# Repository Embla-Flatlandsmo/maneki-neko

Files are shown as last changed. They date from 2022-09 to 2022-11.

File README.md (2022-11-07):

# Maneki Neko
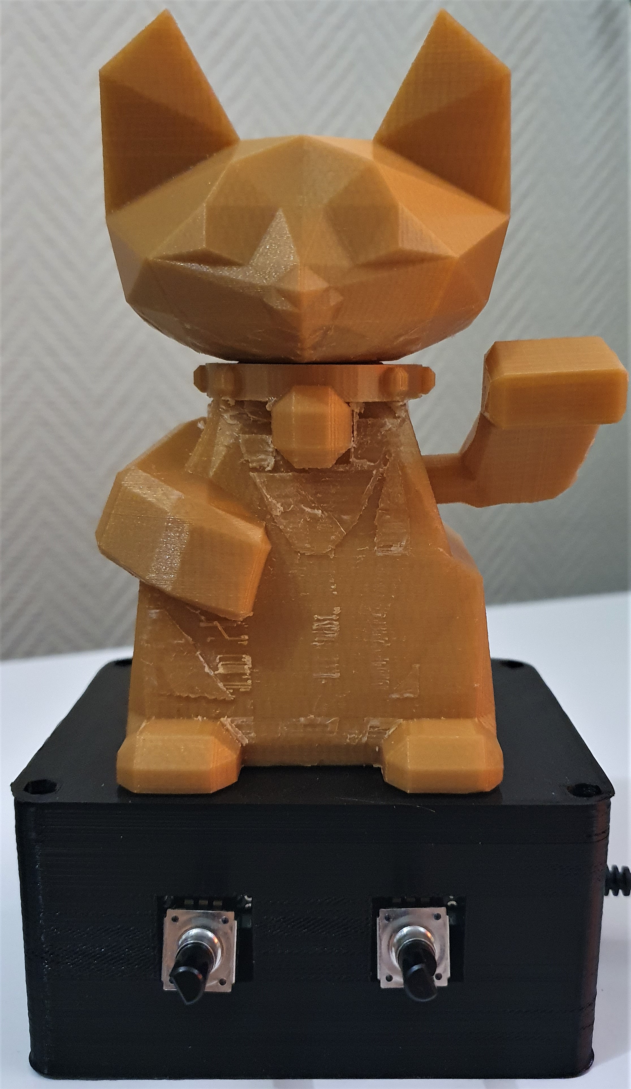
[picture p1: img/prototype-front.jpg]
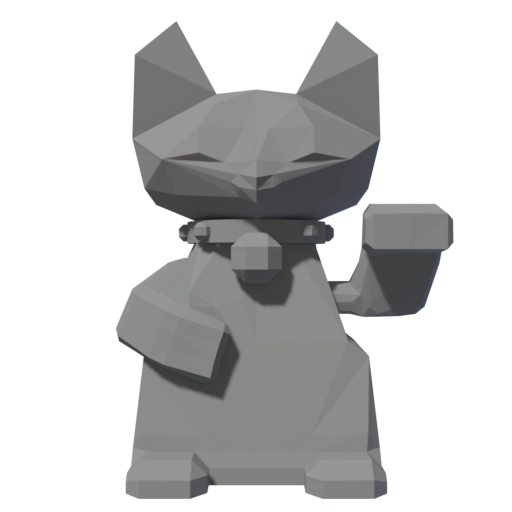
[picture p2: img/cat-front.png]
 

The 3D model is made by [Mats N. Olsen](https://www.matsnolsen.com/)

## Project structure
| Folder | Description |
| --- | --- |
| `code` | Software for the microcontroller unit |
| `production` | Models for 3D printing the parts |
| `schematics` | Images describing the way the electronics are wired |

## Hardware description
The project supports using both [nRF52840 DK](https://www.nordicsemi.com/Products/Development-hardware/nrf52840-dk) and [Adafruit ItsyBitsy nRF52840 Express](https://learn.adafruit.com/adafruit-itsybitsy-nrf52840-express). The enclosure is made for the ItsyBitsy, but `enclosure.scad` has been included so you can make it fit for a different board if you want.

### nRF 52840 DK
#### Wiring
| Pin | Name |
| --- | --- |
| P1.10 | Encoder 1 Line A |
| P1.11 | Encoder 1 Line B |
| P0.27 | Encoder 2 Line A |
| P0.26 | Encoder 2 Line B |
| P0.13 | Servo PWM output | 

### Adafruit ItsyBitsy nRF52840 Express
A full schematic has been made for the ItsyBitsy nRF52840 Express:

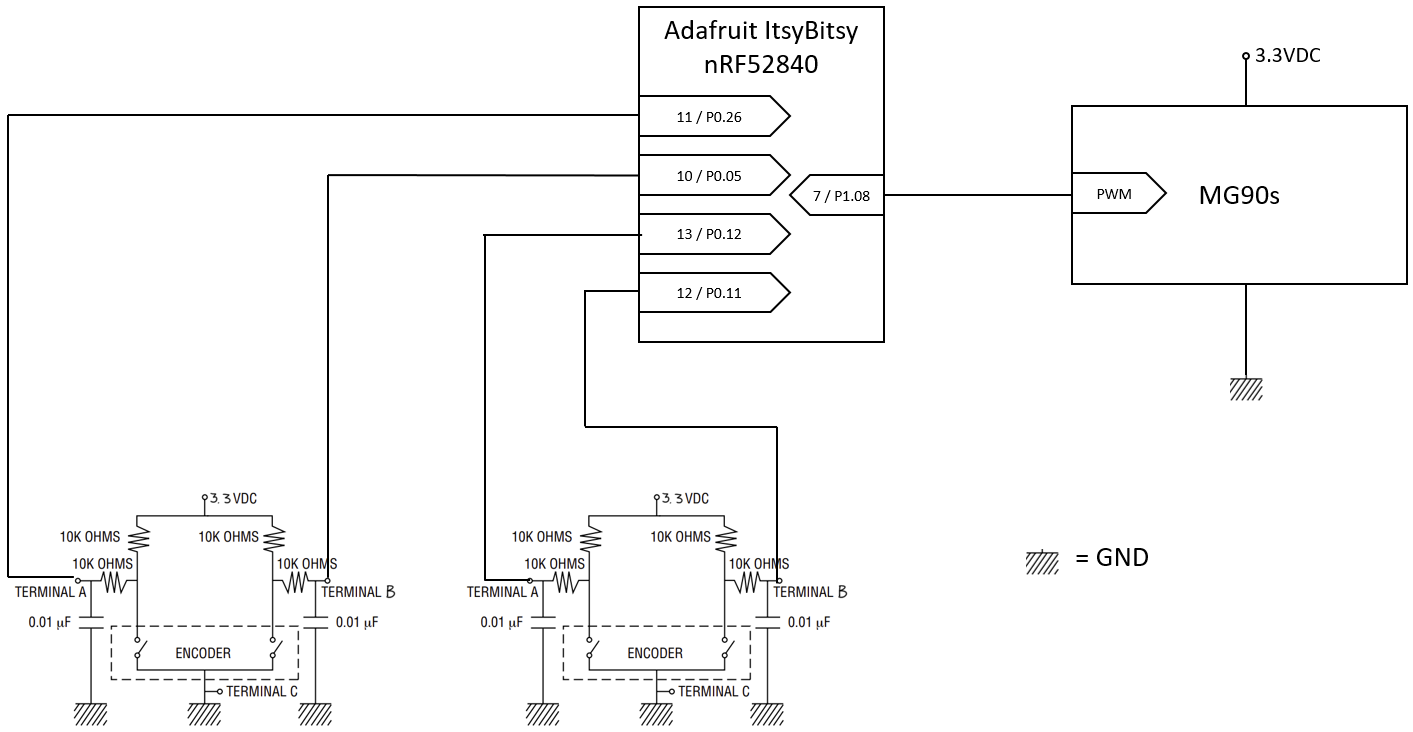
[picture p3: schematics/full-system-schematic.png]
Full system schematic for ItsyBitsy


#### Wiring
| Pin | Name |
| --- | --- |
| 13 | Encoder 1 Line A |
| 12 | Encoder 1 Line B |
| 11 | Encoder 2 Line A |
| 10 | Encoder 2 Line B |
| 7 | Servo PWM output | 

## Software Description
This project uses the [nRF Connect SDK v2.0.2](https://developer.nordicsemi.com/nRF_Connect_SDK/doc/2.0.2/nrf/index.html).
### Setup using the nRF Connect SDK Toolchain Manager
Prerequisite: [nRF Command Line Tools](https://www.nordicsemi.com/Products/Development-tools/nRF-Command-Line-Tools/Download?lang=en#infotabs)
1. **Install ncs v2.0.2**: Follow [nRF Connect SDK (ncs) setup tutorial](https://developer.nordicsemi.com/nRF_Connect_SDK/doc/2.0.2/nrf/gs_assistant.html) to install the nRF Connect SDK (ncs) toolchain.
2. Make sure you are able to build and program a basic project following [the nRF Connect SDK building tutorial](https://developer.nordicsemi.com/nRF_Connect_SDK/doc/latest/nrf/gs_programming.html)

3. **Clone this project into the ncs installation folder**: After installing nRF Connect SDK v2.0.2, open command prompt through the toolchain manager. Then, type `git clone https://github.com/Embla-Flatlandsmo/maneki-neko`

### First time setup for Adafruit ItsyBitsy nRF52840
Before building for the first time, you must copy the folder `code/boards/adafruit_itsybitsy_nrf52840` into the `boards/arm/` directory of your zephyr installation. 

> For example, if ncs is installed at `C:/ncs/v2.0.2` then you would copy the folder so it resides at `C:/ncs/v2.0.2/zephyr/boards/arm/adafruit_itsybitsy_nrf52840`

Before flashing, you must update the Adafruit UF2 bootloader [(see tutorial)](https://learn.adafruit.com/introducing-the-adafruit-nrf52840-feather/update-bootloader)

### Building and Flashing
Before building the project, make sure you are able to build and program a basic project following [the nRF Connect SDK building tutorial](https://developer.nordicsemi.com/nRF_Connect_SDK/doc/latest/nrf/gs_programming.html).

> For both of the boards, follow the steps for [building in the command line](https://developer.nordicsemi.com/nRF_Connect_SDK/doc/2.0.2/nrf/gs_programming.html#gs-programming-cmd).

#### Adafruit ItsyBitsy nRF52840 Express
1. Navigate to `maneki-neko/code` and build the program by calling `west build -b adafruit_itsybitsy_nrf52840`
2. Connect the ItsyBitsy to your host computer using USB
3. Tap the reset button twice quickly to enter bootloader mode
4. Flash the image by dragging and dropping the file `maneki-neko/code/build/zephyr/zephyr.uf2` into the `ITSY840BOOT` drive
5. The program should now run on your device

#### nRF52840 DK
1. Navigate to `maneki-neko/code` and build the program by calling `west build -b nrf52840dk_nrf52840`
2. Connect the nRF52840 DK to your computer using USB
3. Call `west flash`
4. The program should now run on your device

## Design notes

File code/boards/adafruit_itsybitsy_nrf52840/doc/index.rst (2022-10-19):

.. _adafruit_itsybitsy_nrf52840:

Adafruit ItsyBitsy nRF52840
#############################

Overview
********

The Adafruit ItsyBitsy nRF52840 Express is a small (36 mm x 18 mm) ARM
development board with an onboard RGB LED, USB port, 2 MB of QSPI flash,
and range of I/O broken out onto 21 GPIO pins.

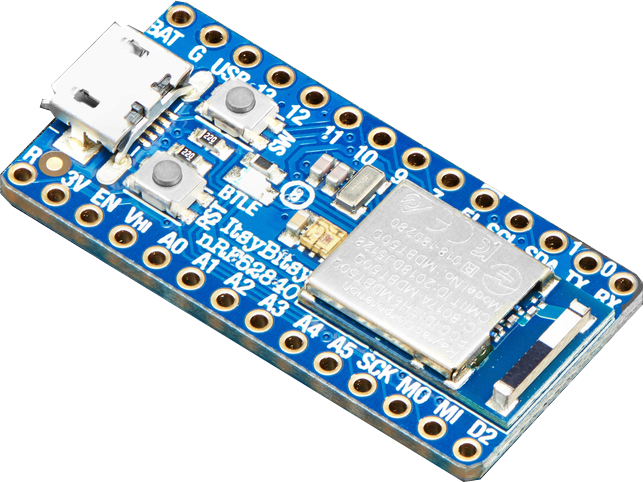
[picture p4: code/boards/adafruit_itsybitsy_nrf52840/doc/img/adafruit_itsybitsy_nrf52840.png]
Adafruit ItsyBitsy nRF52840 Express


Hardware
********
- nRF52840 ARM Cortex-M4F CPU at 64MHz
- 1 MB of flash memory and 256 KB of SRAM
- 2 MB of QSPI flash
- A user LED
- A user switch
- An RGB DotStar LED
- Native USB port
- One reset button

Supported Features
==================

The Adafruit Feather nRF52840 board configuration supports the
following hardware features:

+-----------+------------+----------------------+
| Interface | Controller | Driver/Component     |
+===========+============+======================+
| ADC       | on-chip    | adc                  |
+-----------+------------+----------------------+
| CLOCK     | on-chip    | clock_control        |
+-----------+------------+----------------------+
| FLASH     | on-chip    | flash                |
+-----------+------------+----------------------+
| GPIO      | on-chip    | gpio                 |
+-----------+------------+----------------------+
| I2C       | on-chip    | i2c                  |
+-----------+------------+----------------------+
| MPU       | on-chip    | arch/arm             |
+-----------+------------+----------------------+
| NVIC      | on-chip    | arch/arm             |
+-----------+------------+----------------------+
| PWM       | on-chip    | pwm                  |
+-----------+------------+----------------------+
| RADIO     | on-chip    | Bluetooth,           |
|           |            | ieee802154           |
+-----------+------------+----------------------+
| RTC       | on-chip    | system clock         |
+-----------+------------+----------------------+
| SPI       | on-chip    | spi                  |
+-----------+------------+----------------------+
| UART      | on-chip    | serial               |
+-----------+------------+----------------------+
| USB       | on-chip    | usb                  |
+-----------+------------+----------------------+
| WDT       | on-chip    | watchdog             |
+-----------+------------+----------------------+

Other hardware features have not been enabled yet for this board.

Connections and IOs
===================

The `Adafruit ItsyBitsy nRF52840 Express Learn site`_ has detailed
information about the board including `pinouts`_ and the `schematic`_.

LED
---

* LED0 (red) = P0.06
* LED1 (Adafruit DotStar)
    * DATA = P0.08
    * CLK = P1.09

Push buttons
------------

* SWITCH = P0.29
* RESET = P0.18

Testing LEDs and buttons on the Adafruit ItsyBitsy nRF52840 Express
*******************************************************************
The :ref:`button-sample` sample lets you test the buttons (switches) and the red LED.
The :ref:`blinky-sample` sample lets you test the red LED.

The DotStar LED has been implemented as a SPI device and can be tested
with the :ref:`led_apa102_sample` sample application.

You can build and flash the examples to make sure Zephyr is running correctly on
your board. The button and LED definitions can be found in
:zephyr_file:`boards/arm/adafruit_itsybitsy_nrf52840/adafruit_itsybitsy_nrf52840.dts`.

Programming and Debugging
*************************
The ItsyBitsy ships with the BOSSA compatible UF2 bootloader.  The
bootloader can be entered by quickly tapping the reset button twice.

First time setup
================
Some versions of this board were shipped with a buggy bootloader.
Ensure that the bootloader is up to date by following the
`Adafruit UF2 Bootloader update`_ tutorial.

Flashing
========
Flashing is done by dragging and dropping the built Zephyr UF2-file
into the :code:`ITSY840BOOT` drive.

#. Build the Zephyr kernel and the :ref:`blinky-sample`
   sample application:

   .. zephyr-app-commands::
      :zephyr-app: samples/basic/blinky
      :board: adafruit_itsybitsy_nrf52840
      :goals: build
      :compact:

#. Connect the ItsyBitsy to your host computer using USB

#. Tap the reset button twice quickly to enter bootloader mode

#. Flash the image:

   Drag and drop the file :code:`samples/basic/blinky/build/zephyr/zephyr.uf2`
   into :code:`ITSY840BOOT`

The device will disconnect and you should see the red LED blink.

References
**********

.. target-notes::

.. _Adafruit ItsyBitsy nRF52840 Express Learn site:
    https://learn.adafruit.com/adafruit-itsybitsy-nrf52840-express

.. _pinouts:
    https://learn.adafruit.com/adafruit-itsybitsy-nrf52840-express/pinouts

.. _schematic:
    https://learn.adafruit.com/adafruit-itsybitsy-nrf52840-express/downloads

.. _Adafruit UF2 Bootloader update:
    https://learn.adafruit.com/introducing-the-adafruit-nrf52840-feather/update-bootloader

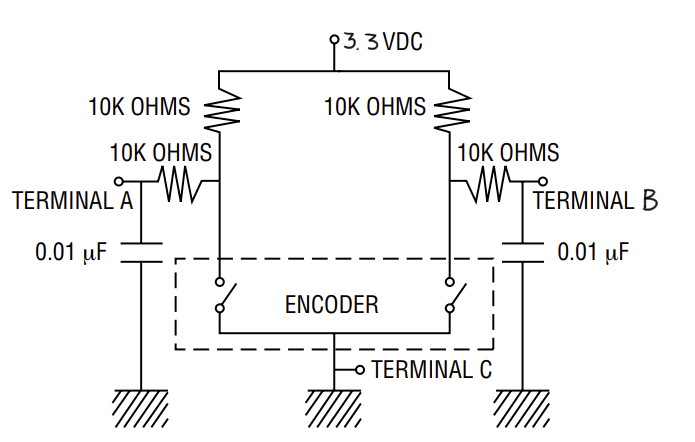
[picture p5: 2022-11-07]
schematics/single-encoder-circuit.png

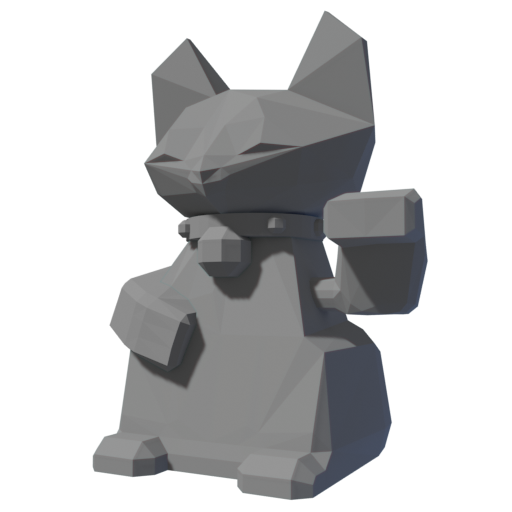
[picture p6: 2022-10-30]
img/cat-3-4.png

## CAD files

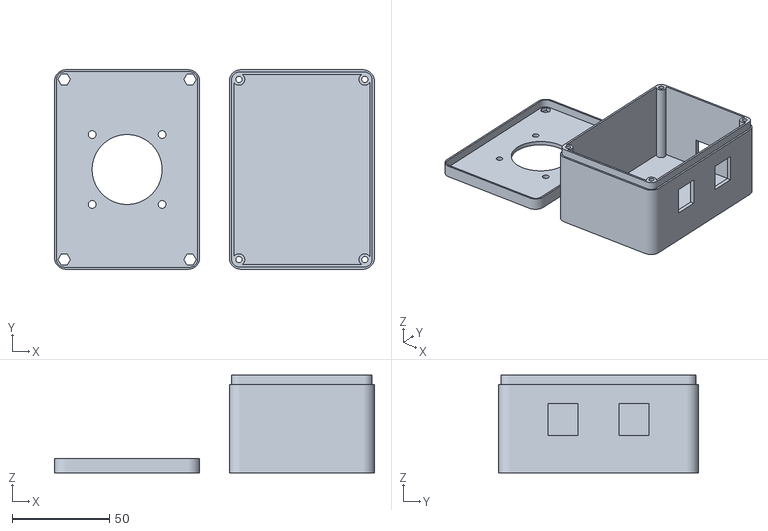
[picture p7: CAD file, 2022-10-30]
production/enclosure.stl
164.8 x 102.8 x 50.4

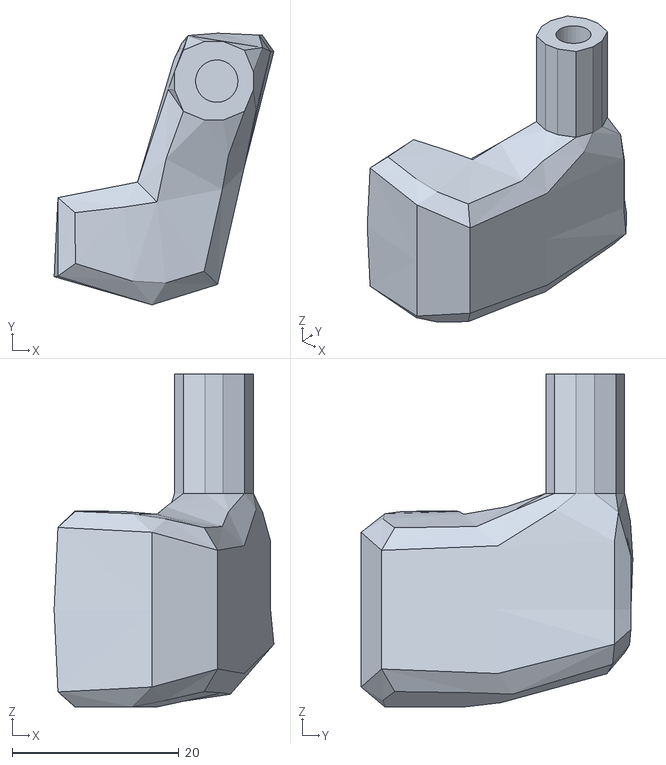
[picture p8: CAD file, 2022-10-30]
production/maneki-neko.stl
26.4 x 32.6 x 39.9

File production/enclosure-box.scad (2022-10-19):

$fn=100;




translate([-w/2-10,0,d+bpt+tpt])
rotate(a=180, v=[0,1,0])
box_top();
translate([w/2+10,0,0])
box_bottom();
             

//*************************************************//
//PARAMETERS
//*************************************************//
//BOX
//--------------------------------------------------
// For PLA printing, things should be in mulitples of 0.4 (standard nozzle thickness)
//inner box width + tolerances
w=70;
//inner box length + tolerances
h=98;
//inner box depth 
d=44;
//wall tickness
wt=2.4;
//bottom plate tickness
bpt=2.4;
//top plate tickness
tpt=2.4;
//top cutout depth
cd=4.8;
//top cutout tickness
cwt=1.2;
//--------------------------------------------------
//BOARD MOUNTING HOLES
//--------------------------------------------------
//position
cx=0;
cy=0;
//holes size (radius)
chs_i=1.5;
chs_o=4;
//distancer height
dsth=3;
//holes distance h
chd_h=90;
//holes distance v
chd_v=90;
//--------------------------------------------------
//TOP PART MOUNTING HOLES
//--------------------------------------------------
//position
cx1=0;
cy1=0;
//holes size (radius)
chs_i1=1.6;
chs_o1=3;
//holes distance h
chd_h1=h-2*chs_i1-2;
//holes distance v
chd_v1=w-2*chs_i1-2;


//--------------------------------------------------
//I/O HOLES
//--------------------------------------------------

usb_hole_padding = 2;
usb_hole_width = 10.6;
usb_hole_height = 8.5;
usb_offset_z = 12; // Offset to center of usb hole


encoder_hole_padding = 1;
encoder_hole_height = 13.5;
encoder_hole_width = 12.5;
encoder_hole_spacing = 24;
encoder_offset_z = 25; // Offset to center of encoder hole

top_hole_radius = 20;
//*************************************************//
//*************************************************//
//MODULES
//*************************************************//

//top box part          
module box_top()
{
        difference()
        {
            union()
            {
                difference()
                {
                    translate([ 0, 0, d+bpt-cd-0.2])     
                    rounded_cube( w+2*wt, h+2*wt, tpt+cd+0.2, 6);
                    
                    translate([ 0, 0,  d+bpt-cd-1])
                    rounded_cube( w+2*cwt+0.3, h+2*cwt+0.3, cd+1, 4);
                }
                /*************************/
                
                //add here...
                
                /*************************/
            }
            //TOP PART HOLES
            tph_t_cut();
            /*************************/
            
            //subtract here... 
            tph_t_electronics_hole();
            /*************************/ 
        }
}
//bottom box
module box_bottom()
{
    difference()
    {
        union()
        {
            difference()
            {
                rounded_cube( w+2*wt, h+2*wt, d+bpt, 6);
                
                translate([ 0, 0, -cd])
                difference()
                {
                    translate([ 0, 0,  d+bpt])
                    rounded_cube( w+2*wt+1, h+2*wt+1, cd+1, 4);

                    translate([ 0, 0,  d+bpt-1])
                    rounded_cube( w+2*cwt, h+2*cwt, cd+3, 4);
                }
                translate([ 0, 0, bpt])
                rounded_cube( w, h, d+bpt, 4);
            }
            //BOARD DISTANCER
            //board_distancer();
            //TOP PLATE DISTANCER
            top_distancer();
            /*************************/
            
            //add here...
            
            /*************************/
        }
        
        //BOARD HOLES
        //bh_cut();
        //TOP PART HOLES
        tph_b_cut();
        /*************************/
        
        //subtract here...
        bh_io_usb();
        bh_io_holes();
        /*************************/
  
    }
}

/****************************************************/
module board_distancer()
{
    translate([cx,cy,0])
    {              
        translate([+chd_h/2,chd_v/2,0])
        cylinder(r=chs_o,h=bpt+dsth);
        translate([-chd_h/2,chd_v/2,0])
        cylinder(r=chs_o,h=bpt+dsth);
        translate([+chd_h/2,-chd_v/2,0])
        cylinder(r=chs_o,h=bpt+dsth);
        translate([-chd_h/2,-chd_v/2,0])
        cylinder(r=chs_o,h=bpt+dsth);
    }
}
module top_distancer()
{
    translate([cx1,cy1,0])
    {
        translate([-chd_v1/2, chd_h1/2, 0])   
        cylinder(r=chs_o1,h=d+bpt);
        translate([-chd_v1/2, -chd_h1/2, 0])   
        cylinder(r=chs_o1,h=d+bpt);
        translate([chd_v1/2, chd_h1/2, 0])   
        cylinder(r=chs_o1,h=d+bpt);
        translate([chd_v1/2, -chd_h1/2, 0])   
        cylinder(r=chs_o1,h=d+bpt);
    }
}
module bh_cut()
{
    translate([cx,cy,0])
    {  
        translate([-chd_h/2,-chd_v/2,-1])
        cylinder(r=chs_i,h=bpt+dsth+2);
        translate([+chd_h/2,-chd_v/2,-1])
        cylinder(r=chs_i,h=bpt+dsth+2);
        translate([-chd_h/2,chd_v/2,-1])
        cylinder(r=chs_i,h=bpt+dsth+2);
        translate([+chd_h/2,chd_v/2,-1])
        cylinder(r=chs_i,h=bpt+dsth+2);
        
        translate([-chd_h/2,-chd_v/2,1.3])
        fhex(5.5,3);
        translate([+chd_h/2,-chd_v/2,1.3])
        fhex(5.5,3);
        translate([-chd_h/2,chd_v/2,1.3])
        fhex(5.5,3);
        translate([+chd_h/2,chd_v/2,1.3])
        fhex(5.5,3);
    }
}


module bh_io_holes()
{
    bh_encoder_hole();
    mirror([0, 1, 0])
        bh_encoder_hole();
}

module bh_encoder_hole()
{
    translate([
    w/2+wt/2, 
    encoder_hole_spacing/2+encoder_hole_width/2+encoder_hole_padding, 
    bpt+encoder_offset_z+encoder_hole_padding
    ])
        cube([2*wt, encoder_hole_width+encoder_hole_padding, encoder_hole_height+encoder_hole_padding], center=true);
}

module bh_io_usb()
{
    
    translate([0, h/2+wt/2, bpt+usb_offset_z+usb_hole_padding])
        cube([usb_hole_width+usb_hole_padding, 2*wt, bpt+usb_hole_height+usb_hole_padding], center=true);
}

module tph_t_electronics_hole()
{
    translate([ 0, 0, d]) 
        cylinder(h=4*tpt, r=top_hole_radius);
}

module tph_t_cut()
{
    translate([cx1,cy1,0])
    {
        translate([-chd_v1/2, chd_h1/2, -2])   
        cylinder(r=chs_i1,h=d+bpt+tpt+3);
        translate([chd_v1/2, chd_h1/2, -2])   
        cylinder(r=chs_i1,h=d+bpt+tpt+3);
    
        translate([-chd_v1/2, -chd_h1/2, -2])   
        cylinder(r=chs_i1,h=d+bpt+tpt+3);
        translate([chd_v1/2, -chd_h1/2, -2])   
        cylinder(r=chs_i1,h=d+bpt+tpt+3);
        
        translate([-chd_v1/2, chd_h1/2, d+bpt+tpt-1.3]) 
        fhex(5.5,3);
        
        translate([chd_v1/2, chd_h1/2, d+bpt+tpt-1.3])  
        fhex(5.5,3);
    
        translate([-chd_v1/2, -chd_h1/2, d+bpt+tpt-1.3])   
        fhex(5.5,3);
        
        translate([chd_v1/2, -chd_h1/2, d+bpt+tpt-1.3])   
        fhex(5.5,3);
    
    }   
}
module tph_b_cut()
{
    translate([cx1,cy1,0])
    {
        translate([-chd_v1/2, chd_h1/2, -2])   
        cylinder(r=chs_i1,h=d+bpt+3);
        translate([chd_v1/2, chd_h1/2, -2])   
        cylinder(r=chs_i1,h=d+bpt+3);
    
        translate([-chd_v1/2, -chd_h1/2, -2])   
        cylinder(r=chs_i1,h=d+bpt+3);
        translate([chd_v1/2, -chd_h1/2, -2])   
        cylinder(r=chs_i1,h=d+bpt+3);
        
        //translate([-chd_v1/2, chd_h1/2, -1]) 
        //cylinder(r=3,h=4);
        
        //translate([chd_v1/2, chd_h1/2, -1])  
        //cylinder(r=3,h=4);
    
        //translate([-chd_v1/2, -chd_h1/2, -1])   
        //cylinder(r=3,h=4);
        
        //translate([chd_v1/2, -chd_h1/2, -1])   
        //cylinder(r=3,h=4); 
    
    }   
}


module rounded_cube( x, y, z, r)
{
    translate([-x/2+r,-y/2+r,0])
    linear_extrude(height=z)
    minkowski() 
    {
        square([x-2*r,y-2*r],true);
        translate([x/2-r,y/2-r,0])
        circle(r);

    }
}

module fhex(wid,height)
{
    hull()
    {
        cube([wid/1.7,wid,height],center = true);
        rotate([0,0,120])cube([wid/1.7,wid,height],center = true);
        rotate([0,0,240])cube([wid/1.7,wid,height],center = true);
    }
}

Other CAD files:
production/enclosure.scad

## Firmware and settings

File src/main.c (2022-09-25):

/*
 * Copyright (c) 2019 Nordic Semiconductor ASA
 *
 * SPDX-License-Identifier: LicenseRef-Nordic-5-Clause
 */

#include <app_event_manager.h>
#include <zephyr/logging/log.h>

#define MODULE main

LOG_MODULE_REGISTER(MODULE);

void main(void)
{
	if (app_event_manager_init()) {
		LOG_ERR("Application Event Manager not initialized");
	} else {
		// module_set_state(MODULE_STATE_READY);
	}
}

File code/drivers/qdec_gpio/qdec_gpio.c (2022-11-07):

#include <devicetree.h>
#include <drivers/sensor.h>
#include <drivers/gpio.h>

#include <logging/log.h>
LOG_MODULE_REGISTER(sensor_qdec_gpio, CONFIG_SENSOR_LOG_LEVEL);

#define DT_DRV_COMPAT nordic_qdec_gpio
#define QDEC_GPIO_INIT_PRIORITY 41

#define FULL_ANGLE 360

struct qdec_gpio_cb_container
{
    struct gpio_callback cb;
    struct device *dev;
};

struct qdec_gpio_data
{
    uint8_t prev_state_a;
    uint8_t prev_state_b;
    int32_t counter;
    int32_t fetched_counter;
    sensor_trigger_handler_t data_ready_handler;
};

struct qdec_gpio_conf
{
    struct gpio_dt_spec gpio_a;
    struct qdec_gpio_cb_container gpio_a_cb_c;
    struct gpio_dt_spec gpio_b;
    struct qdec_gpio_cb_container gpio_b_cb_c;
    int32_t ticks_per_rotation;
};

static int qdec_gpio_sample_fetch(const struct device *dev, enum sensor_channel chan)
{
    if (!(chan == SENSOR_CHAN_ALL || chan == SENSOR_CHAN_ROTATION))
    {
        LOG_ERR("Invalid channel %d. Only SENSOR_CHAN_ALL and SENSOR_CHAN_ROTATION are supported.", chan);
        return -ENOTSUP;
    }

    struct qdec_gpio_data *data = dev->data;
    unsigned int key = irq_lock();
    data->fetched_counter = data->counter;
    irq_unlock(key);

    return 0;
}

static int qdec_gpio_channel_get(const struct device *dev, enum sensor_channel chan, struct sensor_value *val)
{
    if (chan != SENSOR_CHAN_ROTATION)
    {
        LOG_ERR("Invalid channel %d. Only SENSOR_CHAN_ROTATION is supported.", chan);
        return -ENOTSUP;
    }

    const struct qdec_gpio_conf *conf = dev->config;
    const struct qdec_gpio_data *data = dev->data;

    int32_t steps = conf->ticks_per_rotation;

    int32_t counter = data->fetched_counter;

    val->val1 = (counter * FULL_ANGLE) / steps;

    val->val2 = (counter * FULL_ANGLE) % steps;
    val->val2 *= 1000000;
    val->val2 /= steps;
    return 0;
}

static int qdec_gpio_trigger_set(const struct device *dev, const struct sensor_trigger *trig, sensor_trigger_handler_t handler)
{
    struct qdec_gpio_data *data = dev->data;

    if (trig->type != SENSOR_TRIG_DATA_READY)
    {
        LOG_ERR("Invalid trigger type %d. Only SENSOR_TRIG_DATA_READY is supported.", trig->type);
        return -ENOTSUP;
    }

    if ((trig->chan != SENSOR_CHAN_ALL) &&
        (trig->chan != SENSOR_CHAN_ROTATION))
    {
        LOG_ERR("Invalid trigger channel %d. Only SENSOR_CHAN_ROTATION is supported.", trig->chan);
        return -ENOTSUP;
    }

    unsigned int key = irq_lock();
    data->data_ready_handler = handler;
    irq_unlock(key);

    return 0;
}

static void qdec_line_callback(const struct device *port, struct gpio_callback *cb, uint32_t pins)
{
    // Decoding partially taken from https://electronics.stackexchange.com/a/360638
    static int8_t lookup_table[16] = {
        0, // 00 to 00
       -1, // 00 to 01
        1, // 00 to 10
        2, // 00 to 11

        1, // 01 to 00 
        0, // 01 to 01
        2, // 01 to 10
       -1, // 01 to 11

       -1, // 10 to 00 
        2, // 10 to 01
        0, // 10 to 10
        1, // 10 to 11

        2, // 11 to 00
        1, // 11 to 01
       -1, // 11 to 10
        0  // 11 to 11
    };

    struct device *dev = CONTAINER_OF(cb, struct qdec_gpio_cb_container, cb)->dev;
    struct qdec_gpio_data *data = dev->data;
    struct qdec_gpio_conf *conf = dev->config;

    uint8_t old_a = data->prev_state_a;
    uint8_t old_b = data->prev_state_b;

    uint8_t new_a = gpio_pin_get(port, conf->gpio_a.pin);
    uint8_t new_b = gpio_pin_get(port, conf->gpio_b.pin);

    data->prev_state_a = new_a;
    data->prev_state_b = new_b;
    uint8_t movement_index = (old_a << 3) + (old_b << 2) + (new_a << 1) + new_b;
    if (lookup_table[movement_index] > 1)
    {
        LOG_WRN("Quadrature decoder made invalid transition. old_a: %d, old_b: %d, new_a: %d, new_b: %d", old_a, old_b, new_a, new_b);
        return;
    }

    data->counter += lookup_table[movement_index];

    if (data->data_ready_handler)
    {
        struct sensor_trigger trig = {
            .type = SENSOR_TRIG_DATA_READY,
            .chan = SENSOR_CHAN_ROTATION,
        };
        data->data_ready_handler(dev, &trig);
    }
}
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

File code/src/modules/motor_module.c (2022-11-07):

/*
 * Copyright (c) 2018 - 2019 Nordic Semiconductor ASA
 *
 * SPDX-License-Identifier: LicenseRef-Nordic-5-Clause
 */

#include <assert.h>
#include <limits.h>

#include <zephyr/kernel.h>
#include <zephyr/types.h>

#include <zephyr/sys/util.h>
#include <device.h>
#include <drivers/pwm.h>

#include "events/encoder_module_event.h"
#include <caf/events/module_state_event.h>

#define MODULE motor_module

#include <zephyr/logging/log.h>
LOG_MODULE_REGISTER(MODULE, CONFIG_MOTOR_MODULE_LOG_LEVEL);

static const struct pwm_dt_spec servo = PWM_DT_SPEC_GET(DT_NODELABEL(servo));
static const uint32_t min_pulse = DT_PROP(DT_NODELABEL(servo), min_pulse);
static const uint32_t max_pulse = DT_PROP(DT_NODELABEL(servo), max_pulse);

static const uint32_t pulse_range = (max_pulse-min_pulse)/2;

#if IS_ENABLED(CONFIG_MOTOR_MODULE_USE_BTN_INPUT)
#include <caf/events/button_event.h>
#define BTN_INCREASE_PERIOD 0
#define BTN_DECREASE_PERIOD 2
#define BTN_INCREASE_AMPLITUDE 1
#define BTN_DECREASE_AMPLITUDE 3
#endif /* CONFIG_MOTOR_MODULE_USE_BTN_INPUT */

#define AMPLITUDE_STEP CONFIG_MOTOR_MODULE_AMPLITUDE_STEP
#define PERIOD_STEP CONFIG_MOTOR_MODULE_PERIOD_STEP

#define MAX_PERIOD_MSEC CONFIG_MOTOR_MODULE_MAX_PERIOD_MSEC
#define MIN_PERIOD_MSEC CONFIG_MOTOR_MODULE_MIN_PERIOD_MSEC

uint32_t amplitude = 100;
uint32_t motor_time_period_msec = MIN_PERIOD_MSEC;

/*================= UTILITY FUNCTIONS =================*/

/**
 * @brief Maps a value in range [input_start, input_end] to the range [output_start, output_end]
 * 
 * @param input value to map
 * @param input_start Start of value range (minimum)
 * @param input_end End of value range (maximum)
 * @param output_start Start of new range (minimum)
 * @param output_end End of new range (maximum)
 * @return uint32_t Value, in new range
 */
uint32_t map_range(uint32_t input, uint32_t input_start, uint32_t input_end, uint32_t output_start, uint32_t output_end)
{
    return output_start + ((output_end - output_start) / (input_end - input_start)) * (input - input_start);
}

static void update_period(float value)
{
    if (value > 0) 
    {
        if (motor_time_period_msec >= MAX_PERIOD_MSEC)
        {
            motor_time_period_msec = MAX_PERIOD_MSEC;
            LOG_DBG("Max period width reached.");
            return;
        }
        motor_time_period_msec += PERIOD_STEP;
        LOG_DBG("increasing period");
        return;
    }

    if (value < 0) 
    {
        if (motor_time_period_msec <= MIN_PERIOD_MSEC)
        {
            motor_time_period_msec = MIN_PERIOD_MSEC;
            LOG_DBG("Min period width reached.");
            return;
        }
        motor_time_period_msec -= PERIOD_STEP;
        LOG_DBG("Decreasing period");
        return;
    }
    return;
}

static void update_amplitude(float value) 
{
    if (value > 0) {
        if (amplitude >= 100)
        {
            amplitude = 100;
            LOG_DBG("Max amplitude reached.");
            return;
        }
        amplitude += AMPLITUDE_STEP;
        LOG_DBG("Increasing amplitude");
        return;
    }

    if (value < 0) {
        if (amplitude <= 0)
        {
            amplitude = 0;
            LOG_DBG("Min amplitude reached.");
            return;
        }
        amplitude -= AMPLITUDE_STEP;
        LOG_DBG("Decreasing Amplitude");
        return;
    }

    return;
}


/*================= EVENT HANDLERS =================*/

static bool handle_encoder_module_event(const struct encoder_module_event *evt)
{
    switch (evt->type)
    {
        case ENCODER_A_EVT_DATA_SEND:
            update_period(evt->data.rot_val);
            break;
        case ENCODER_B_EVT_DATA_SEND:
            update_amplitude(evt->data.rot_val);
            break;
        default:
            break;
    }
    return false;
}


#if IS_ENABLED(CONFIG_MOTOR_MODULE_USE_BTN_INPUT)
static bool handle_button_event(const struct button_event *evt)
{
	if (evt->pressed) {
		switch (evt->key_id) {
		case BTN_INCREASE_PERIOD:
            update_period(1.0);
			break;
		case BTN_DECREASE_PERIOD:
            update_period(-1.0);
			break;
        case BTN_INCREASE_AMPLITUDE:
            update_amplitude(1.0);
            break;
        case BTN_DECREASE_AMPLITUDE:
            update_amplitude(-1.0);
            break;
		default:
			break;
		}
	}
	return false;
}
#endif /* CONFIG_MOTOR_MODULE_USE_BTN_INPUT */

static bool app_event_handler(const struct app_event_header *aeh)
{
    if (is_encoder_module_event(aeh))
    {
        return handle_encoder_module_event(cast_encoder_module_event(aeh));
    }

#if IS_ENABLED(CONFIG_MOTOR_MODULE_USE_BTN_INPUT)
	if (is_button_event(aeh)) {
		return handle_button_event(cast_button_event(aeh));
	}
#endif /* CONFIG_MOTOR_MODULE_USE_BTN_INPUT */

	if (is_module_state_event(aeh)) {
        /* No setup necessary since it is done in module_thread_fn */
		return false;
	}
	/* Event not handled but subscribed. */
	__ASSERT_NO_MSG(false);
    return false;

}

/*================= MODULE THREAD =================*/
static int setup(void)
{
	int ret;

	if (!device_is_ready(servo.dev)) {
		LOG_ERR("Error: PWM device %s is not ready\n", servo.dev->name);
		return 0;
	}
    return 0;
}

static void module_thread_fn(void)
{
    LOG_DBG("Initializing motor module.");
    LOG_DBG("Pulse width: [%d, %d] (ns)", min_pulse, max_pulse);
    LOG_DBG("Arm rotation period range: [%d, %d] (ms)", MIN_PERIOD_MSEC, MAX_PERIOD_MSEC);
	int err;

	err = setup();
	if (err) {
		LOG_ERR("setup, error: %d", err);
	}

    int ret;
    static int up_or_down = 1;

    while(true)
    {   
        uint32_t pulse_width_offset = map_range(amplitude, 0, 100, 0, pulse_range);
        uint32_t pulse_width = min_pulse+pulse_range+up_or_down*pulse_width_offset;
        up_or_down *= -1;
        ret = pwm_set_pulse_dt(&servo, pulse_width);
		if (ret < 0) {
			LOG_ERR("Error %d: failed to set pulse width\n", ret);
			return;
		}
        k_sleep(K_MSEC(motor_time_period_msec));
    }
}

K_THREAD_DEFINE(motor_module_thread, CONFIG_MOTOR_THREAD_STACK_SIZE,
		module_thread_fn, NULL, NULL, NULL,
		K_HIGHEST_APPLICATION_THREAD_PRIO, 0, 0);
APP_EVENT_LISTENER(MODULE, app_event_handler);
APP_EVENT_SUBSCRIBE(MODULE, encoder_module_event);
APP_EVENT_SUBSCRIBE(MODULE, module_state_event);

#if IS_ENABLED(CONFIG_MOTOR_MODULE_USE_BTN_INPUT)
APP_EVENT_SUBSCRIBE(MODULE, button_event);
#endif /* CONFIG_MOTOR_MODULE_USE_BTN_INPUT */

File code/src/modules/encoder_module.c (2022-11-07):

/*
 * Copyright (c) 2021 Nordic Semiconductor ASA
 *
 * SPDX-License-Identifier: LicenseRef-Nordic-5-Clause
 */


#include <zephyr/kernel.h>

#define MODULE encoder_module
#include <caf/events/module_state_event.h>
#include <app_event_manager.h>
#include <zephyr/settings/settings.h>
#include <drivers/sensor.h>
#include "modules_common.h"
#include "events/encoder_module_event.h"

#include <zephyr/logging/log.h>
LOG_MODULE_REGISTER(MODULE, CONFIG_ENCODER_MODULE_LOG_LEVEL);

static const int64_t minimum_update_interval_msec = (1000/CONFIG_ENCODER_MAX_MESSAGE_FREQUENCY);

static struct sensor_trigger trig_a;
static struct sensor_trigger trig_b;

static double rot_a;
static double rot_b;
static int64_t encoder_a_delta_time;
static int64_t encoder_b_delta_time;

static void trigger_a_handler(const struct device *dev, const struct sensor_trigger* trig)
{
	struct sensor_value rot;
	int err;
	err = sensor_sample_fetch(dev);
	if (err != 0)
	{
		LOG_ERR("sensor_sample_fetch error: %d\n", err);
		return;
	}
	err = sensor_channel_get(dev, SENSOR_CHAN_ROTATION, &rot);
	if (err != 0)
	{
		LOG_ERR("sensor_channel_get error: %d\nF", err);
		return;
	}

	double new_rot_a = sensor_value_to_double(&rot);
	float delta_rot = rot_a - new_rot_a;
	rot_a = new_rot_a;

	int64_t delta_time_a = k_uptime_delta(&encoder_a_delta_time);
	if (delta_time_a >= minimum_update_interval_msec) {
		struct encoder_module_event *encoder_module_event = new_encoder_module_event();
		encoder_module_event->type = ENCODER_A_EVT_DATA_SEND;
		encoder_module_event->data.rot_val = delta_rot;
		APP_EVENT_SUBMIT(encoder_module_event);
	}
}

static void trigger_b_handler(const struct device *dev, const struct sensor_trigger* trig)
{
	struct sensor_value rot;
	int err;
	err = sensor_sample_fetch(dev);
	if (err != 0)
	{
		LOG_ERR("sensor_sample_fetch error: %d\n", err);
		return;
	}
	err = sensor_channel_get(dev, SENSOR_CHAN_ROTATION, &rot);
	if (err != 0)
	{
		LOG_ERR("sensor_channel_get error: %d\n", err);
		return;
	}
	
	double new_rot_b = sensor_value_to_double(&rot);
	float delta_rot = rot_b - new_rot_b;
	rot_b = new_rot_b;
	int64_t delta_time_b = k_uptime_delta(&encoder_b_delta_time);
	if (delta_time_b >= minimum_update_interval_msec) {
		struct encoder_module_event *encoder_module_event = new_encoder_module_event();
		encoder_module_event->type = ENCODER_B_EVT_DATA_SEND;
		encoder_module_event->data.rot_val = delta_rot;
		APP_EVENT_SUBMIT(encoder_module_event);
	}
}

static int module_init(void)
{
	const struct device* encoder_a_dev = device_get_binding(DT_LABEL(DT_NODELABEL(qdeca)));
	const struct device* encoder_b_dev = device_get_binding(DT_LABEL(DT_NODELABEL(qdecb)));
	if (encoder_a_dev == NULL || encoder_b_dev == NULL)
	{
		LOG_ERR("Failed to get bindings for encoder devices");
		return -ENODEV;
	}

	trig_a.type = SENSOR_TRIG_DATA_READY;
	trig_a.chan = SENSOR_CHAN_ROTATION;

	trig_b.type = SENSOR_TRIG_DATA_READY;
	trig_b.chan = SENSOR_CHAN_ROTATION;
	int err;
	err = sensor_trigger_set(encoder_a_dev, &trig_a, trigger_a_handler);
	if (err)
	{
		LOG_ERR("sensor_trigger_set for encoderb error: %d", err);
		return err;
	}

	err = sensor_trigger_set(encoder_b_dev, &trig_b, trigger_b_handler);
	if (err)
	{
		LOG_ERR("sensor_trigger_set for encoderb error: %d", err);
		return err;
	}
	LOG_DBG("Minimum update period: %lld [ms]", minimum_update_interval_msec);

	return 0;
}

static bool app_event_handler(const struct app_event_header *aeh)
{
	if (is_module_state_event(aeh)) {
		const struct module_state_event *event = cast_module_state_event(aeh);

		if (check_state(event, MODULE_ID(main), MODULE_STATE_READY)) {
			
            if (module_init())
            {
                LOG_ERR("ENCODER module init failed");

                return false;
            }
            LOG_INF("ENCODER module initialized");
			const int64_t current_time = k_uptime_get();
			encoder_a_delta_time = current_time;
			encoder_b_delta_time = current_time;
            module_set_state(MODULE_STATE_READY);
		}

		return false;
	}
	/* Event not handled but subscribed. */
	__ASSERT_NO_MSG(false);
	return false;
}

APP_EVENT_LISTENER(MODULE, app_event_handler);
APP_EVENT_SUBSCRIBE(MODULE, module_state_event);

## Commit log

2022-09-27 add servo_motor sample
    [pwm-servo.yaml]
2022-09-27 structural changes in prep for motor test
2022-09-27 set up buttons to work in place of encoder
2022-10-04 buttons increase oscillation amplitude/frequency of motor
    [pwm-servo.yaml]
2022-10-04 try to make qdec module work. Can't read encoder values
2022-10-04 single-pin encoder polling works on button sample
2022-10-05 Make both encoders work
2022-10-08 correct itsybitsy driver
2022-10-15 Make motor control work with encoders
2022-10-19 clean up motor module
2022-10-19 add 3D printing files for enclosure
    [enclosure-box.scad, enclosure-box.stl]
2022-10-30 add production files, update readme
    [enclosure-box.stl, enclosure.scad, enclosure.stl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]
2022-11-07 Cleanup and improve documentation
    [pwm-servo.yaml]
2022-11-07 rename qdec->encoder
